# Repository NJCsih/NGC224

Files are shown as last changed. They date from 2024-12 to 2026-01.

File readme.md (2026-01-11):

# NGC224 | MK4

A 36-key pcb-only fully-split column-staggered keyboard

- Full split, using full-duplex usart over TRRS
- Uses Elite-Pi microcontroller, Arduino Pro Micro back compatible
- Kailh Choc switches, hot-swap mounts, and through-hole diodes
- Gerbers and source kicad files available
- CC-BY-NC-SA Licensed

## Assembly

There is only one known hardware issue: The TRRS jack was placed inset to the pcb, which prevents my TRRS cable from being connected. I filed through the pcb to allow room for the connection. Filing through fiberglass is not exactly fun--I did it with the corner of the board submerged in water, and superglued over the exposed edge. Do not worry about shorting the copper planes together, as both are ground.

I prefer clipping through-hole pins to less than the pcb-width, giving a flush solder joint. However the hot-swap mounts are sharp enough to catch a deskmat, so this is less important on MK4.

## Flashing:

For the Elite-Pi microcontroller, plug in one board at a time, and run the following command to start compilation. Once it is waiting for a board, double press the boot dimple button on the Elite-Pi, and mount with dolphin.

```bash
# Plug in left side
qmk flash -kb ngc224 -km default -c -bl uf2-split-left

# Plug in right side
qmk flash -kb ngc224 -km default -c -bl uf2-split-right
```

## Layouts:
"One does not simply share his emacs configuration, this is all personalized to my quirks and misdemeanors"

I use [Colemak-DH](https://colemakmods.github.io/mod-dh/), chosen due to hand pain issues to minimize finger travel, especially with less usage of the center columns

## BOM:
- 1-each: left and right PCBs
	- As an american I spend \$40 to ship and import a \$9 JLC
- 36: Kailh choc hot-swap mounts
- 36: Kailh choc switches
- 72: through-hole 1N4148 Diodes
- 2: TRRS connectrs
- 1: TRRS cable

## Credits:
- Kicad footprints are from [joe-scotto/scottokeebs](https://github.com/joe-scotto/scottokeebs)

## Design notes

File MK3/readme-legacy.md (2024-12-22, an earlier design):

# NGC224

A small 40% pcb-only fully split ortho, only supporting kialh choc switches.

If there will be a V2, it will likely add mx switch support, or just to make it hotswappable.

* Keyboard Maintainer: [Juliet](https://github.com/NJCsih)
* Hardware Supported: ATmega24U arduino pro micro, choc switches, custom pcb
* Hardware Availability: Pro micro at your discretion, boards are not mass produced.

Pretty sure I've lost the pcb files due to a hard drive failure lol \:cries\:

## Flashing:

I just flash with qmk on the unix command line with:

```bash
# Plug in left side
qmk flash -kb ngc224 -km default -c -bl avrdude-split-left

# Plug in right side
qmk flash -kb ngc224 -km default -c -bl avrdude-split-right
```

This handles the eeprom flashing as well, and works with the atmega24U chips.

I'd like to include a nix flake for the qmk versioning soon, mostly just so that if they fully-depricate c-style configuration in favor of info.json I can just... ignore it forever.

## Layout:

The layout I use is based on the colemak-dh layout, everything except the letters is custom.

I've gone down to 34 buttons, so there's just kinda 14 extra ones hanging out on my keyboard now :p

I do use homerow mods now. From center out they go ctrl, shift, alt, super. The outer thumb buttons are escape and enter when tapped, and num and fn layers when held.

Current "default" layout:
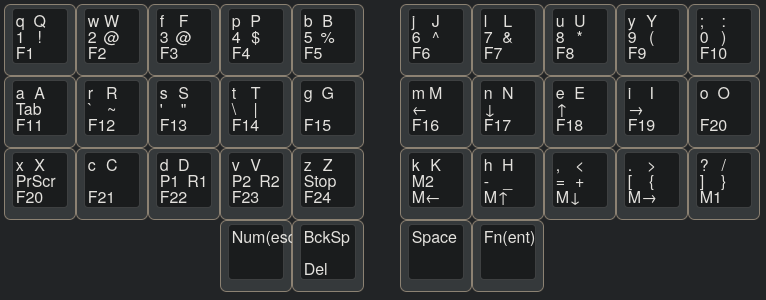
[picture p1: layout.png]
layout


## The future:

I would like to do a v2, which would introduce hotswappable switch mounts, and not feature a broken I2C connection, which has been patched by desoldering the resistors and using serial instead.

I do need to actually print the keycaps, I'll add a photo or two once I do.

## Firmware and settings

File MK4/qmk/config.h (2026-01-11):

#pragma once

// #include "config_common.h"

/* USB Device descriptor parameter */
// #define MANUFACTURER Homebuilt
// #define PRODUCT      Andromeda
// #define VENDOR       NA

#define VENDOR_ID 0x0000
#define PRODUCT_ID 0x0000
#define DEVICE_VER 0x0001
#define MANUFACTURER "NA"
#define PRODUCT "ngc224"

/*
 * There's a different hardware issue which is cool, someone didn't read the I2C
 * sheet well enough :p I'm nixing the resistors and using serial over one of
 * the formerly I2C pins :( better than new pcbs tho I guess The discord was
 * really nice though.
 */

/* Split keyboard descriptors */
#define EE_HANDS
#define SPLIT_USB_DETECT

// #define MASTER_RIGHT

/* key matrix size */
#define MATRIX_ROWS 8 // magic? it complains if they're too low? idk
#define MATRIX_COLS 5

// Wait I think you double the rows, and then it just implicitly puts the right
// half below the left, you don't need to NO_PIN anything! THAT WORKED!
// EVERYTHING WORKS! :D
#define MATRIX_ROW_PINS {GP20, GP23, GP21, GP9}
#define MATRIX_COL_PINS {GP29, GP28, GP27, GP26, GP22} // Left pins

#define MATRIX_ROW_PINS_RIGHT {GP7, GP8, GP9, GP21}
#define MATRIX_COL_PINS_RIGHT {GP6, GP5, GP4, GP3, GP2} // Left pins

// Using COL2ROW Diodes
#define DIODE_DIRECTION COL2ROW

/* Debounce reduces chatter (unintended double-presses) - set 0 if debouncing is
 * not needed */
#define DEBOUNCE 5

#define SERIAL_USART_FULL_DUPLEX // Enable full duplex operation mode.
#define SERIAL_USART_TX_PIN GP0  // USART TX pin
#define SERIAL_USART_RX_PIN GP1  // USART RX pin
#define SERIAL_PIO_USE_PIO1      // Force the usage of PIO1 peripheral, by default
                                 // the Serial implementation uses the PIO0
                                 // peripheral
